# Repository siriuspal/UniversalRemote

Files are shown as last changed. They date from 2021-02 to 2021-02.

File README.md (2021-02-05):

# UniversalRemote
## Universal IR Remote developed using ESP32, MicroPython, and MQTT

### Background:
I have a LG TV and Yamaha Home Theatre System. I was tired of using two remotes by my side and all universal remotes with macro options were expensive. So I designed an IR Remote which allowed me to use a mobile as a universal remote. The code in this repository is just my specific implementation, however it's easy to expand to any number of remotes and any custom macro.

To capture the required IR Codes, I used generic IR receiver and captured signals on a USB oscilloscope. I decoded the protocol (IR NEC) using PulseView SigRok https://sigrok.org/wiki/PulseView 

IR NEC protocol is described here in detail: https://techdocs.altium.com/display/FPGA/NEC+Infrared+Transmission+Protocol
There are many sources over Internet for IR remote codes - e.g. for LG TV https://gitlab.com/snippets/1690600
For above resource, the format of code was different than what I captured directly using PulseView, so I wrote a helper script to convert format.

### Setup:
#### Hardware:
Generic ESP-WROOM-32 Development Board with USB port  
Generic IR LED  
MOSFET, Resistor, Wires  
USB Cable  
5V USB Power Supply  
#### Enclosure:
Custom 3D Printed Enclosure designed using OnShape  
#### Software:
MicroPython ver 1.13 (esp32-idf3-20200902-v1.13.bin) https://micropython.org/download/esp32/  
umqtt.robust2 (and umqtt.simple2) https://github.com/fizista/micropython-umqtt.robust2  
#### Other:
Raspberry Pi as MQTT Broker  
MQTT Dashboard as Remote https://play.google.com/store/apps/details?id=com.app.vetru.mqttdashboard&hl=en_IN&gl=US  
Wi-Fi Router

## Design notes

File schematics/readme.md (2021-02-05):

A simple schematics for directly driving IR LED.  

In my setup the ESP32 board is placed under TV and home theatre and facing away from these units. Meaning the IR light bounces off the opposite wall or furniture and controls the equipment.  
The LED is powered directly with 5V without any resistor. Since RMT waveform is modulated with 38,222 Hz signal, the pulses are short duration.

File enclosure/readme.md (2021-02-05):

# Mechanical file is designed using OnShape online  

https://cad.onshape.com/documents/f6c111bf281719af73e79788/w/fe446a7dd27b93e9277fb0e3/e/fd8451a165b3e3523bd4e215

The enclosure is specific to my setup - as LED and other parts are handsoldered to the board. 
THe position of the LED is very specific to how I have soldered the components and will change for other people.  

USB connector opening should be made thinner or larger to allow for proper connection with cable. 

Height of the ESP32 board is modified from the standard height because before I designed enclosure, I covered the pins with glue to prevent shorts as board was kept open. This may cause height deviation.

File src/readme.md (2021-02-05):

Normally MicroPython libraries can be installed using upip and they are saved in lib folder. In my case, umqtt.robust2 had some issues (module import failed) so I "sideloaded" it along side code and modified import statement appropriately.  

The "carrier_freq" keyword argument of RMT function of ESP32 is not implemented in MicroPython version earlier than 1.13.

Modify boot.py to add SSID and Password of your Wi-Fi router.  

Modify mqtt.py to add IP address of MQTT Broker.

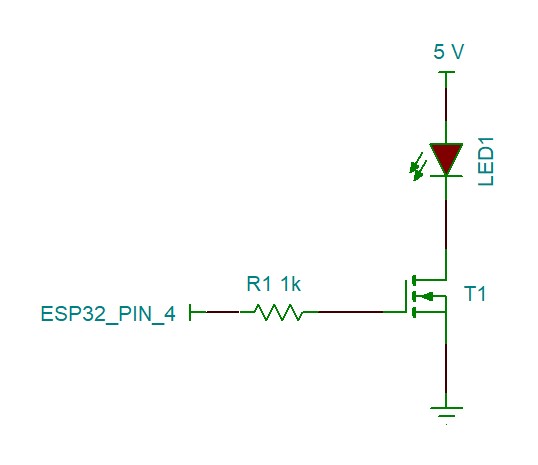
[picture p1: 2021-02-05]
schematics/Schematics.JPG

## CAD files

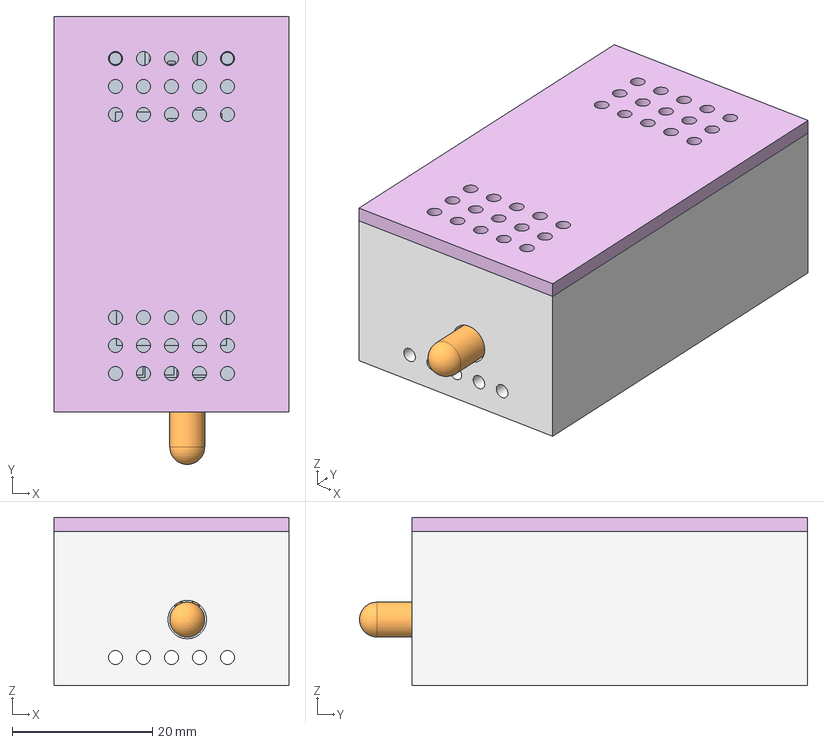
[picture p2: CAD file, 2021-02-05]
enclosure/ESP32 Enclosure with ESP Board.step
33.5 x 64.0 x 24.0 mm
id6
id11
id16
id21
id26
id31
id36
CUI_DEVICES_UJ2-MIBH2-4-SMT x 2
id46
id51
id56
id66
id71
id76
id81
id86
id91
id96
id101
id106
id111
id116
id121
id126
id131
id136
id141
id146
id151
id156
id161
id166
id171
id176
id181
id186
id191
id196
id201
id206
id211
id216
id221
id226
id231
id236
id241
id246
id251
Cover
LED

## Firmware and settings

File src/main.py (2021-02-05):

''' Main file to execute all micropython codes '''

import _thread
import machine
import utime
import mqtt

# Simple implementation for logging
logfile = 'mainlog.txt'


try:
    _thread.start_new_thread(mqtt.start, ())
except Exception as exc:
    with open(logfile, 'a+') as f:
        print(str(exc))
        f.write(str(exc))
        f.write('\n')
    utime.sleep(5)
    machine.reset()

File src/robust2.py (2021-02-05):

''' umqtt.simple2 '''
# I tried to install and use umqtt.simple2 and umqtt.robust2 directly by using upip.
# However even though installation was successful, importing umqtt.robust was failing for some reason.
# So I directly copied files along side the code and modified it suitably to keep dependency intact.
# Using umqtt.robust2 is important as it implements reconnect features -
# Without which IR remote will crash when there is connectivity issues with Broker
# This file is downloaded from https://github.com/fizista/micropython-umqtt.robust2
# Credits to the author.

from utime import ticks_ms, ticks_diff
import simple2


class MQTTClient(simple2.MQTTClient):
    DEBUG = False

    # Information whether we store unsent messages with the flag QoS==0 in the queue.
    KEEP_QOS0 = True
    # Option, limits the possibility of only one unique message being queued.
    NO_QUEUE_DUPS = True
    # Limit the number of unsent messages in the queue.
    MSG_QUEUE_MAX = 5
    # When you reconnect, all existing subscriptions are renewed.
    RESUBSCRIBE = True

    def __init__(self, *args, **kwargs):
        """
        See documentation for `umqtt.simple2.MQTTClient.__init__()`
        """
        super().__init__(*args, **kwargs)
        self.subs = []  # List of stored subscriptions
        self.msg_to_send = []  # Queue with list of messages to send
        self.sub_to_send = []  # Queue with list of subscriptions to send
        # Queue with a list of messages waiting for the server to confirm of the message.
        self.msg_to_confirm = {}
        # Queue with a subscription list waiting for the server to confirm of the subscription
        self.sub_to_confirm = {}
        # We store here if there is a connection problem.
        self.conn_issue = None

    def is_keepalive(self):
        """
        It checks if the connection is active. If the connection is not active at the specified time,
        saves an error message and returns False.

        :return: If the connection is not active at the specified time returns False otherwise True.
        """
        time_from__last_cpackage = ticks_diff(
            ticks_ms(), self.last_cpacket) // 1000
        if 0 < self.keepalive < time_from__last_cpackage:
            self.conn_issue = (simple2.MQTTException(7), 9)
            return False
        return True

    def set_callback_status(self, f):
        """
        See documentation for `umqtt.simple2.MQTTClient.set_callback_status()`
        """
        self._cbstat = f

    def cbstat(self, pid, stat):
        """
        Captured message statuses affect the queue here.

        stat == 0 - the message goes back to the message queue to be sent
        stat == 1 or 2 - the message is removed from the queue
        """
        try:
            self._cbstat(pid, stat)
        except AttributeError:
            pass

        for data, pids in self.msg_to_confirm.items():
            if pid in pids:
                if stat == 0:
                    self.msg_to_send.insert(0, data)
                pids.remove(pid)
                if not pids:
                    self.msg_to_confirm.pop(data)
                return

        for data, pids in self.sub_to_confirm.items():
            if pid in pids:
                if stat == 0:
                    self.sub_to_send.append(data)
                pids.remove(pid)
                if not pids:
                    self.sub_to_confirm.pop(data)

    def connect(self, clean_session=True):
        """
        See documentation for `umqtt.simple2.MQTTClient.connect()`.

        If clean_session==True, then the queues are cleared.

        Connection problems are captured and handled by `is_conn_issue()`
        """
        if clean_session:
            self.msg_to_send[:] = []
            self.msg_to_confirm.clear()
        try:
            out = super().connect(clean_session)
            self.conn_issue = None
            return out
        except (OSError, simple2.MQTTException) as e:
            self.conn_issue = (e, 1)

    def log(self):
        if self.DEBUG:
            if type(self.conn_issue) is tuple:
                conn_issue, issue_place = self.conn_issue
            else:
                conn_issue = self.conn_issue
                issue_place = 0
            place_str = ('?', 'connect', 'publish', 'subscribe',
                         'reconnect', 'sendqueue', 'disconnect', 'ping', 'wait_msg', 'keepalive', 'check_msg')
            print("MQTT (%s): %r" % (place_str[issue_place], conn_issue))

    def reconnect(self):
        """
        The function tries to resume the connection.

        Connection problems are captured and handled by `is_conn_issue()`
        """
        try:
            out = super().connect(False)
            self.conn_issue = None
            return out
        except (OSError, simple2.MQTTException) as e:
            self.conn_issue = (e, 4)
            if self.sock:
                self.sock.close()
                self.sock = None

    def resubscribe(self):
        """
        Function from previously registered subscriptions, sends them again to the server.

        :return:
        """
        for topic, qos in self.subs:
            self.subscribe(topic, qos, False)

    def add_msg_to_send(self, data):
        """
        By overwriting this method, you can control the amount of stored data in the queue.
        This is important because we do not have an infinite amount of memory in the devices.

        Currently, this method limits the queue length to MSG_QUEUE_MAX messages.

        The number of active messages is the sum of messages to be sent with messages awaiting confirmation.

        :param data:
        :return:
        """
        # Before we add data to the queue, it is necessary to release the memory first.
        # Otherwise, we may fall into an infinite loop due to a lack of available memory.
        messages_count = len(self.msg_to_send)
        messages_count += sum(map(len, self.msg_to_confirm.values()))

        while messages_count >= self.MSG_QUEUE_MAX:
            min_msg_to_confirm = min(
                map(lambda x: x[0] if x else 65535, self.msg_to_confirm.values()), default=0)
            if 0 < min_msg_to_confirm < 65535:
                key_to_check = None
                for k, v in self.msg_to_confirm.items():
                    if v and v[0] == min_msg_to_confirm:
                        del v[0]
                        key_to_check = k
                        break
                if key_to_check and key_to_check in self.msg_to_confirm and not self.msg_to_confirm[key_to_check]:
                    self.msg_to_confirm.pop(key_to_check)
            else:
                self.msg_to_send.pop(0)
            messages_count -= 1

        self.msg_to_send.append(data)

    def disconnect(self):
        """
        See documentation for `umqtt.simple2.MQTTClient.disconnect()`
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
